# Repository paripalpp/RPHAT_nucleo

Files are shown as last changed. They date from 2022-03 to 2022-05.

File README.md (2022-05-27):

# RPHAT_nucleo
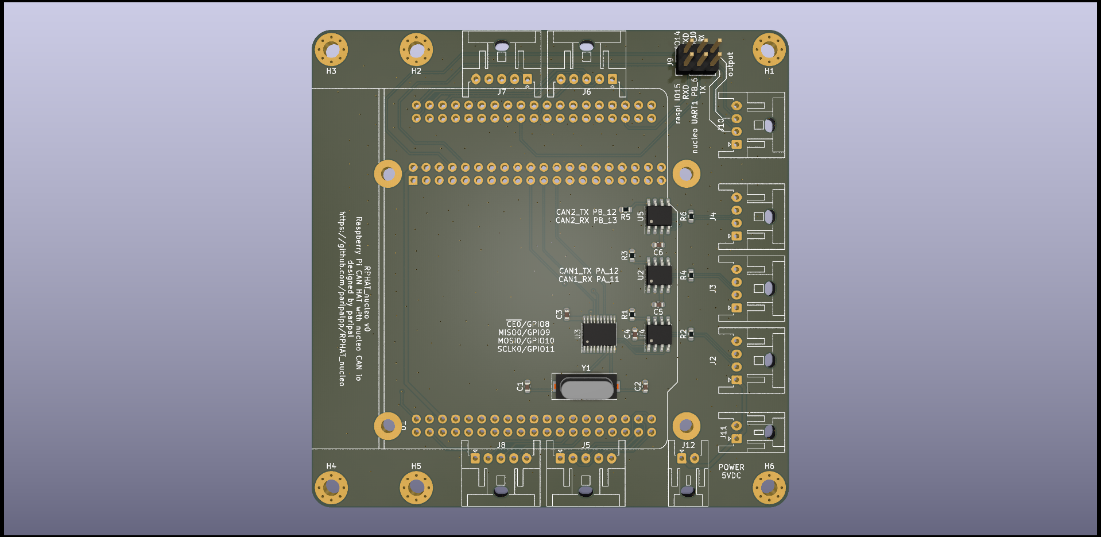
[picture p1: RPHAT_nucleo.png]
3Dimage

# connector
|Connector|pin number|nucleo pin|
|---|---|---|
J5|1|PC_0
J5|2|PC_1
J5|3|PC_2
J5|4|PC_3
J5|5|GND
J6|1|PC_4
J6|2|PC_5
J6|3|PC_6
J6|4|PC_7
J6|5|GND
J7|1|PC_8
J7|2|PC_9
J7|3|PC_10
J7|4|PC_11
J7|5|GND
J8|1|PC_12
J8|2|PC_13
J8|3|PC_14
J8|4|PC_15
J8|5|GND
# 注意！！
V0のボードは CAN2 の PB12 と PB13 がつながってますが、CAN TX と CAN RX が逆なので、使用しない又はプリントを切ってつなぎなおすなどをしてください。
 
V1のボードは解決済み。
# LISENCE
<br />This work is licensed under a <a rel="license" href="http://creativecommons.org/licenses/by/4.0/">Creative Commons Attribution 4.0 International License</a>.
<br />この 作品 は <a rel="license" href="http://creativecommons.org/licenses/by/4.0/">クリエイティブ・コモンズ 表示 4.0 国際 ライセンス</a>の下に提供されています。

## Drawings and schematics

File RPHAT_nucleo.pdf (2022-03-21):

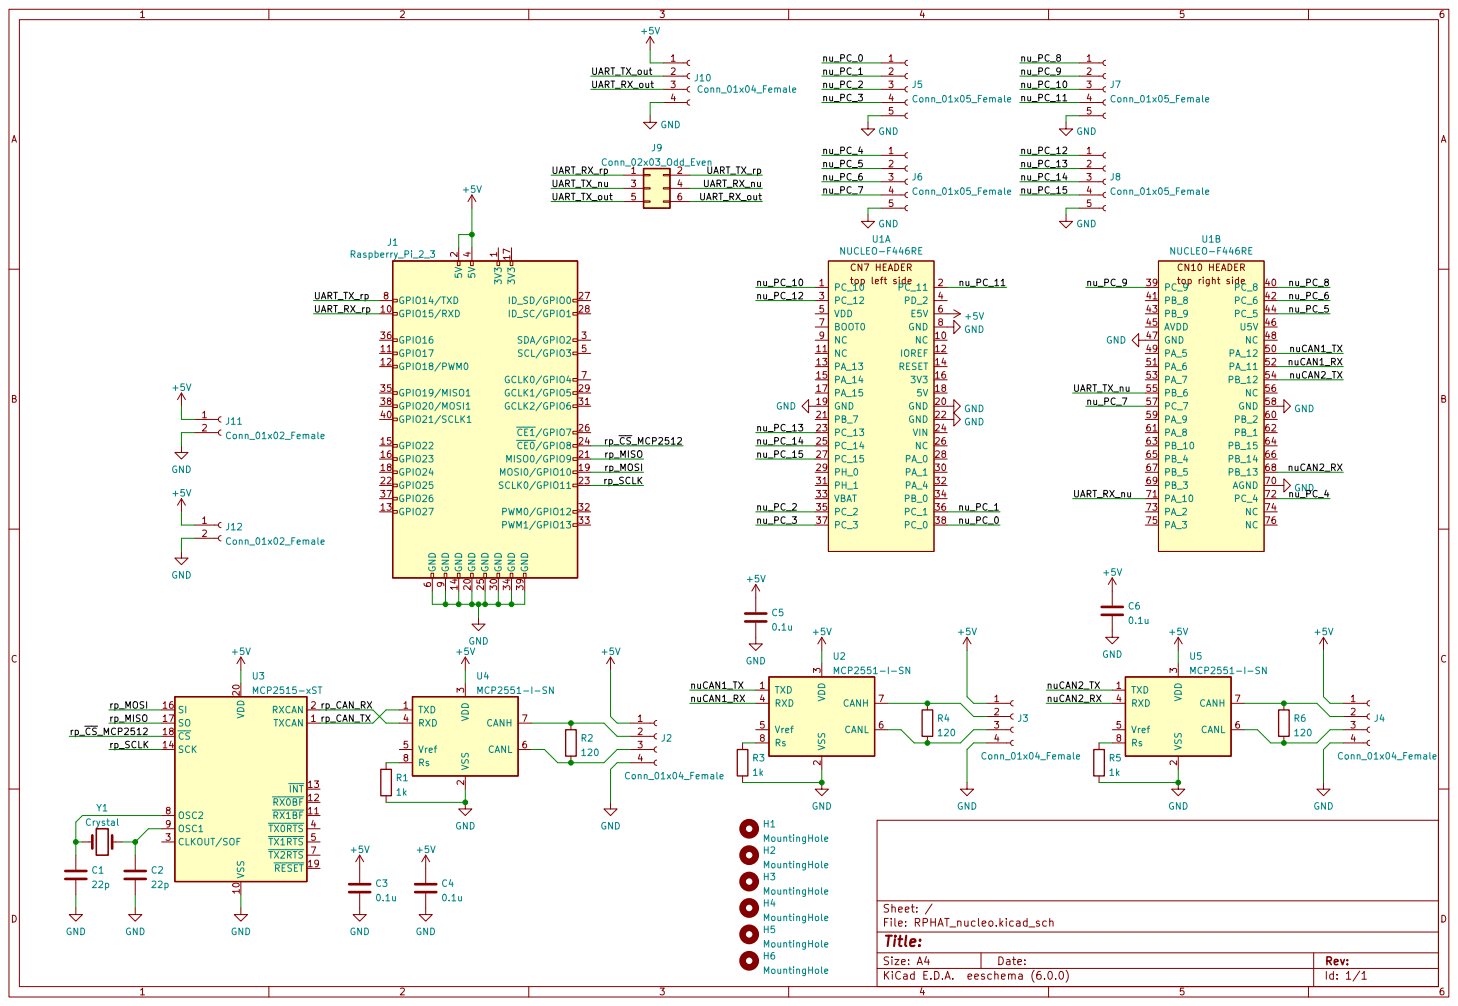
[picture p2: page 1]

3 RXD 4 Vref 5 CANL 6 CANH 7 Rs 8 U2MCP2551-I-SN

3 RXD 4 Vref 5 CANL 6 CANH 7 Rs 8 U5MCP2551-I-SN

3 RXD 4 Vref 5 CANL 6 CANH 7 Rs 8 U4MCP2551-I-SN

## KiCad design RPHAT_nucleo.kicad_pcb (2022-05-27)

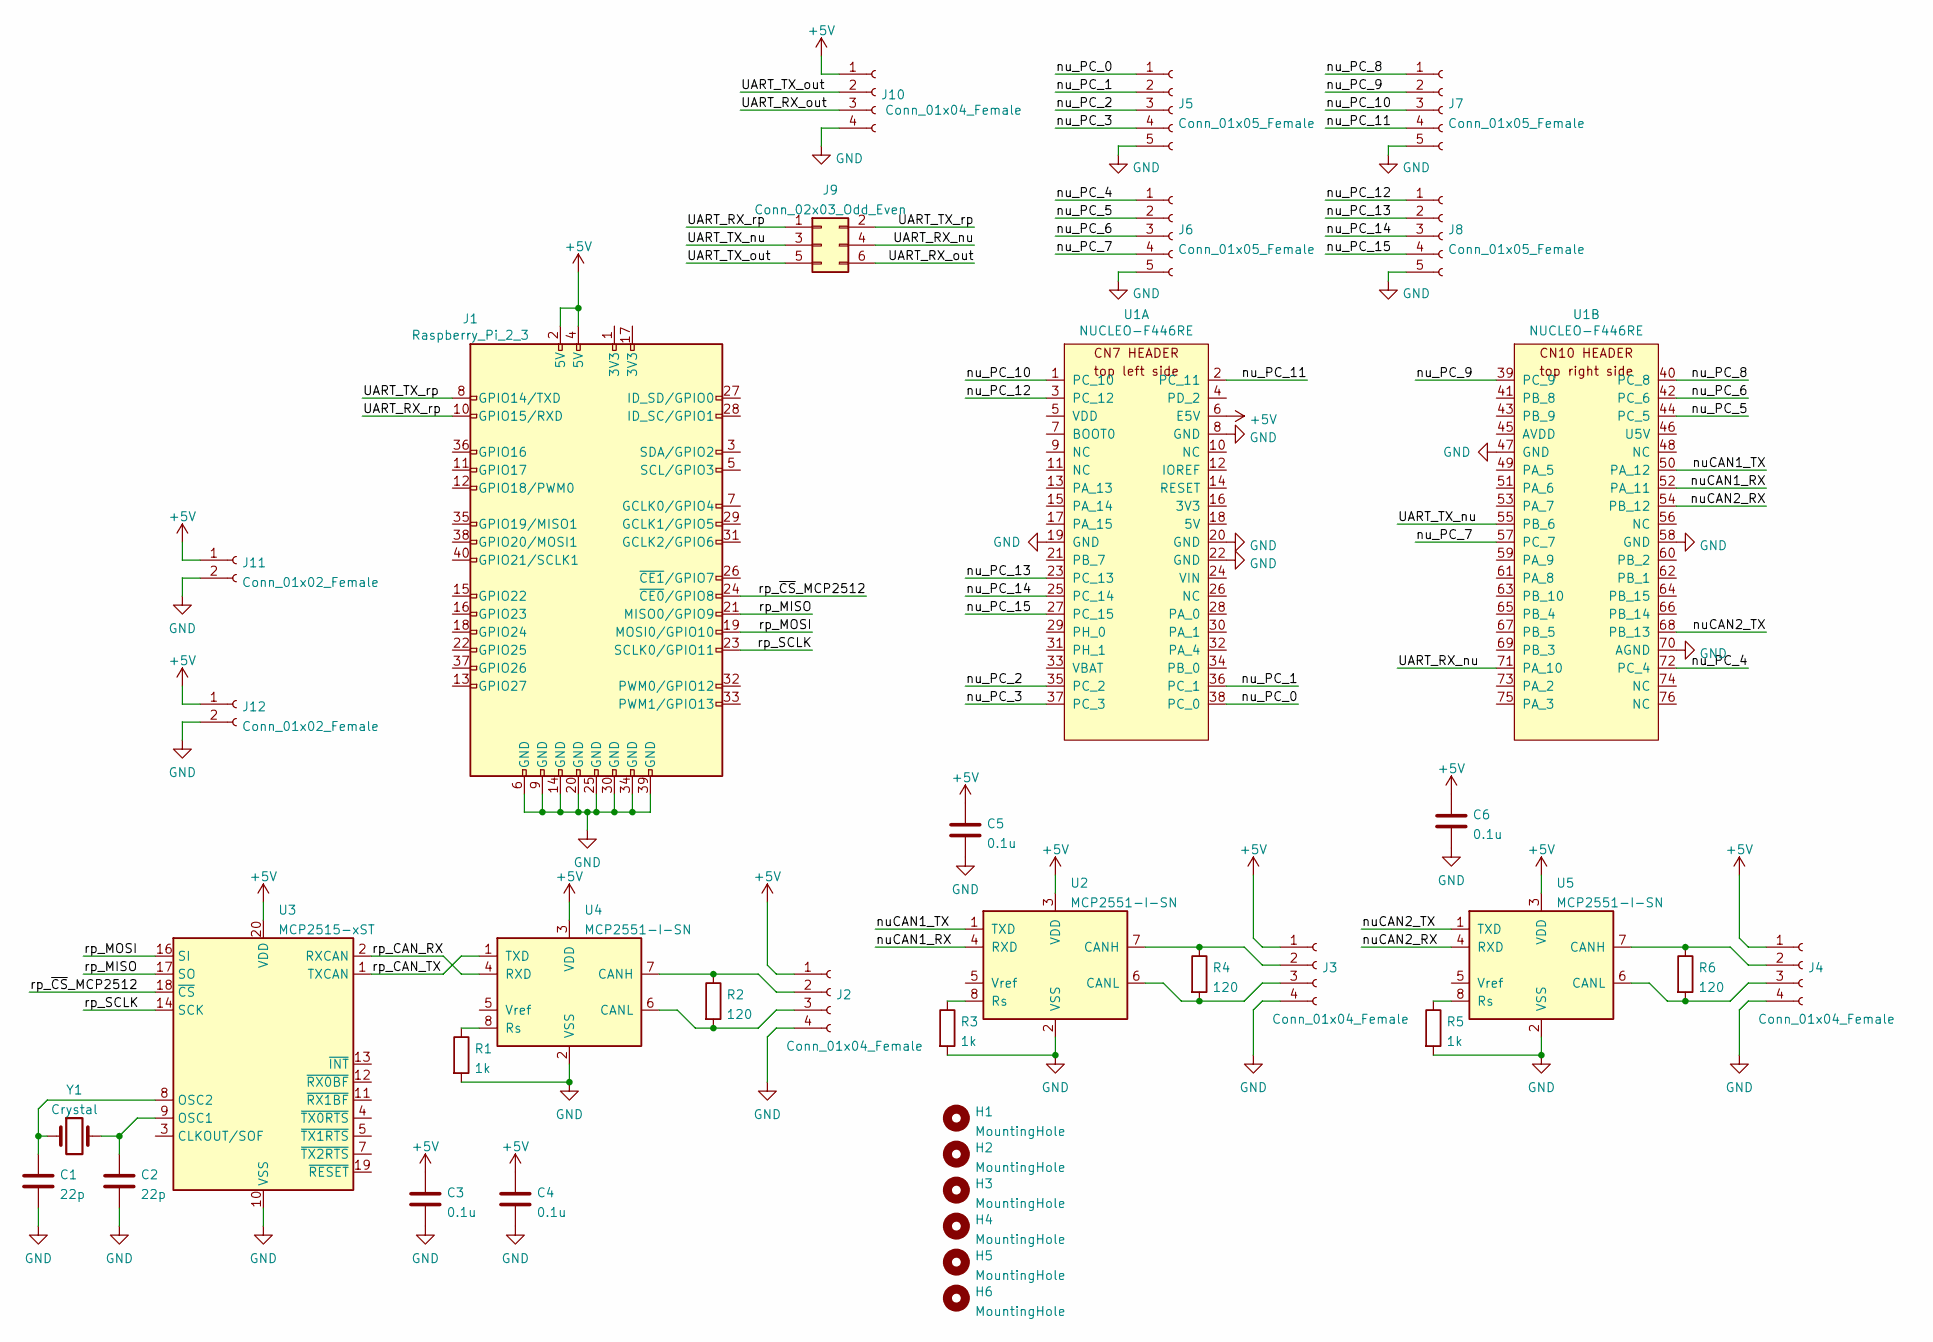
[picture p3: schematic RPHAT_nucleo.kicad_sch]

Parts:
C1, C2: 22p; C_0603_1608Metric
C3, C4, C5, C6: 0.1u; C_0603_1608Metric
H1, H2, H3, H4, H5, H6: MountingHole; MountingHole_3.2mm_M3_Pad_Via
J1: Raspberry_Pi_2_3; RaspberryPi_HAT_Connector_4hole
J2, J3, J4, J10: Conn_01x04_Female; JST_XA_S04B-XASK-1_1x04_P2.50mm_Horizontal
J5, J6, J7, J8: Conn_01x05_Female; JST_XA_S05B-XASK-1_1x05_P2.50mm_Horizontal
J9: Conn_02x03_Odd_Even; PinHeader_2x03_P2.54mm_Vertical
J11, J12: Conn_01x02_Female; JST_XA_S02B-XASK-1_1x02_P2.50mm_Horizontal
R1, R3, R5: 1k; R_0603_1608Metric
R2, R4, R6: 120; R_0603_1608Metric
U1: NUCLEO-F446RE; Nucleo-64_ST_morpho
U2, U4, U5: MCP2551-I-SN; SOIC-8_3.9x4.9mm_P1.27mm
U3: MCP2515-xST; TSSOP-20_4.4x6.5mm_P0.65mm
Y1: Crystal; Crystal_SMD_HC49-SD

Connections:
+5V: C3.1, C4.1, C5.1, C6.1, J1.2 (5V), J1.4 (5V), J2.1, J3.1, J4.1, J10.1, J11.1, J12.1, U1.6 (E5V), U2.3 (VDD), U3.20 (VDD), U4.3 (VDD), U5.3 (VDD)
/UART_RX_nu: J9.4, U1.71 (PA_10)
/UART_RX_out: J9.6, J10.3
/UART_RX_rp: J1.10 (GPIO15/RXD), J9.1
/UART_TX_nu: J9.3, U1.55 (PB_6)
/UART_TX_out: J9.5, J10.2
/UART_TX_rp: J1.8 (GPIO14/TXD), J9.2
/nuCAN1_RX: U1.52 (PA_11), U2.4 (RXD)
/nuCAN1_TX: U1.50 (PA_12), U2.1 (TXD)
/nuCAN2_RX: U1.54 (PB_12), U5.4 (RXD)
/nuCAN2_TX: U1.68 (PB_13), U5.1 (TXD)
/nu_PC_0: J5.1, U1.38 (PC_0)
/nu_PC_1: J5.2, U1.36 (PC_1)
/nu_PC_2: J5.3, U1.35 (PC_2)
/nu_PC_3: J5.4, U1.37 (PC_3)
/nu_PC_4: J6.1, U1.72 (PC_4)
/nu_PC_5: J6.2, U1.44 (PC_5)
/nu_PC_6: J6.3, U1.42 (PC_6)
/nu_PC_7: J6.4, U1.57 (PC_7)
/nu_PC_8: J7.1, U1.40 (PC_8)
/nu_PC_9: J7.2, U1.39 (PC_9)
/nu_PC_10: J7.3, U1.1 (PC_10)
/nu_PC_11: J7.4, U1.2 (PC_11)
/nu_PC_12: J8.1, U1.3 (PC_12)
/nu_PC_13: J8.2, U1.23 (PC_13)
/nu_PC_14: J8.3, U1.25 (PC_14)
/nu_PC_15: J8.4, U1.27 (PC_15)
/rp_CAN_RX: U3.2 (RXCAN), U4.4 (RXD)
/rp_CAN_TX: U3.1 (TXCAN), U4.1 (TXD)
/rp_MISO: J1.21 (MISO0/GPIO9), U3.17 (SO)
/rp_MOSI: J1.19 (MOSI0/GPIO10), U3.16 (SI)
/rp_SCLK: J1.23 (SCLK0/GPIO11), U3.14 (SCK)
/rp_~CS_MCP2512: J1.24 (~CE0/GPIO8), U3.18 (~CS)
GND: C1.2, C2.2, C3.2, C4.2, C5.2, C6.2, J1.6 (GND), J1.9 (GND), J1.14 (GND), J1.20 (GND), J1.25 (GND), J1.30 (GND), J1.34 (GND), J1.39 (GND), J2.4, J3.4, J4.4, J5.5, J6.5, J7.5, J8.5, J10.4, J11.2, J12.2, R1.2, R3.2, R5.2, U1.8 (GND), U1.19 (GND), U1.20 (GND), U1.22 (GND), U1.47 (GND), U1.58 (GND), U1.70 (AGND), U2.2 (VSS), U3.10 (VSS), U4.2 (VSS), U5.2 (VSS)
unnamed: C1.1, U3.8 (OSC2), Y1.1
unnamed: C2.1, U3.9 (OSC1), Y1.2
unnamed: J2.2, R2.1, U4.7 (CANH)
unnamed: J2.3, R2.2, U4.6 (CANL)
unnamed: J3.2, R4.1, U2.7 (CANH)
unnamed: J3.3, R4.2, U2.6 (CANL)
unnamed: J4.2, R6.1, U5.7 (CANH)
unnamed: J4.3, R6.2, U5.6 (CANL)
unnamed: R1.1, U4.8 (Rs)
unnamed: R3.1, U2.8 (Rs)
unnamed: R5.1, U5.8 (Rs)

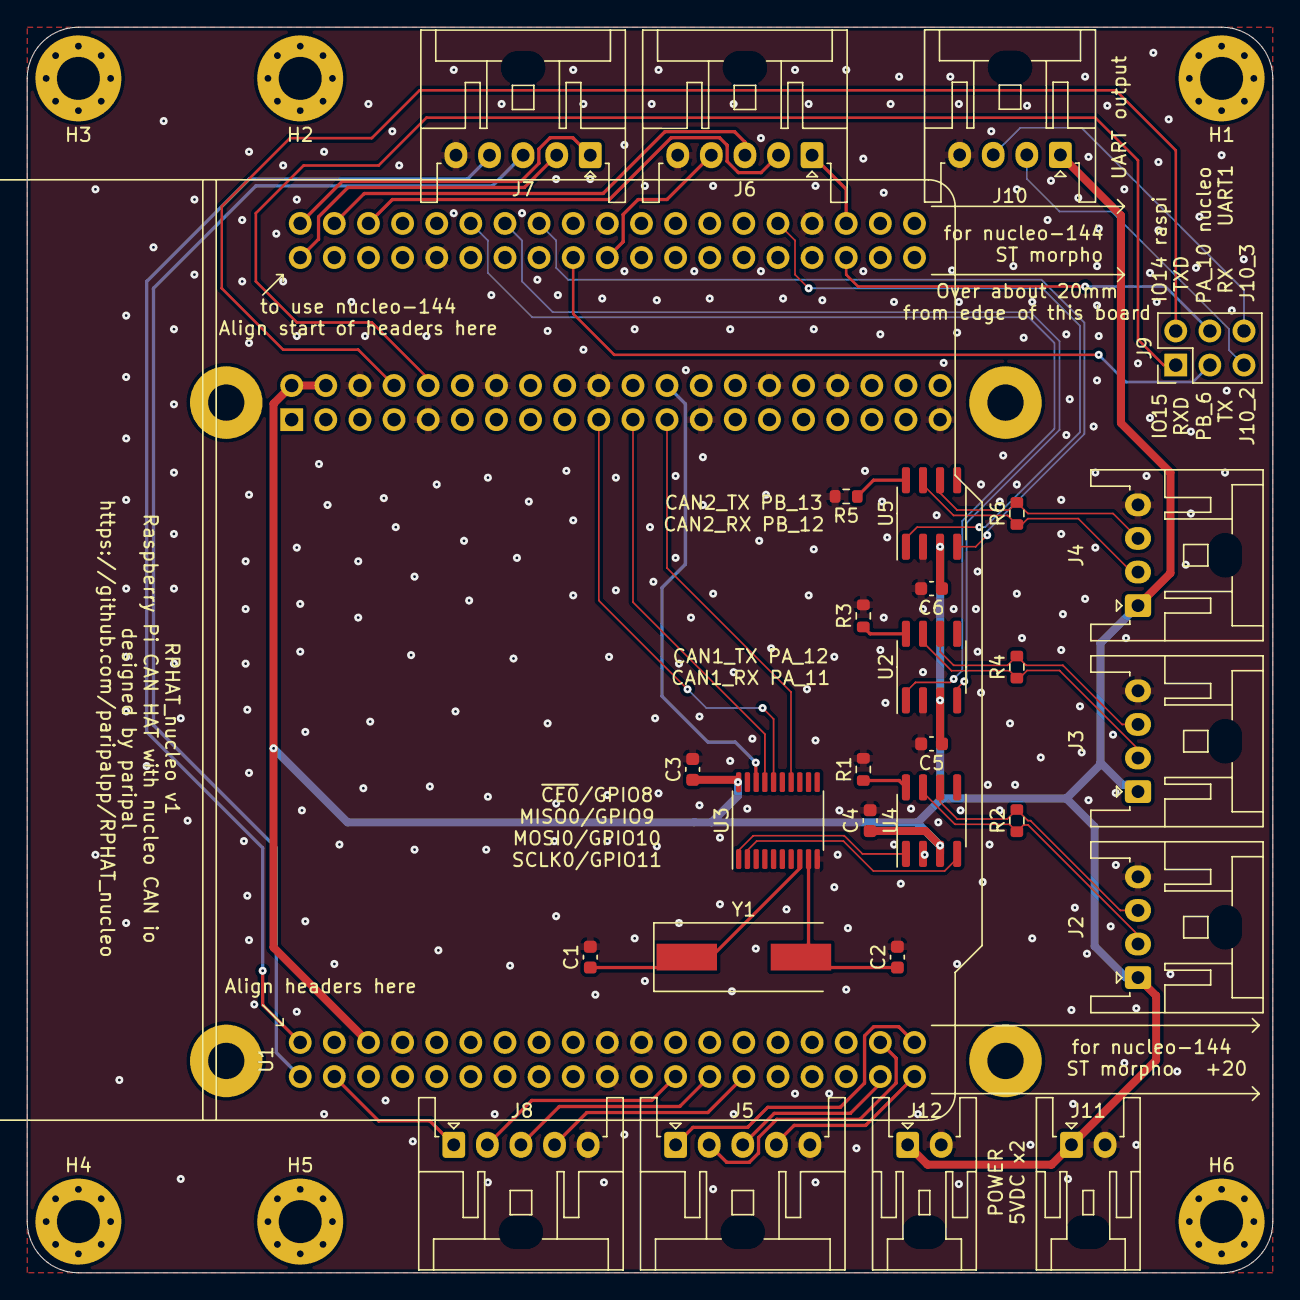
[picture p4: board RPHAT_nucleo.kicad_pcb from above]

Board: 2 copper layers, 92.7 x 92.7 mm, 36 parts (0 on the bottom side), 45 nets.

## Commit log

2021-12-27 to 6.0
    [RPHAT_nucleo.kicad_pcb, RPHAT_nucleo.kicad_sch]
2022-03-18 edit some net class
    [RPHAT_nucleo.kicad_pcb, RPHAT_nucleo.kicad_sch, RPHAT_nucleo.sch]
2022-04-20 Update README.md
    CAN2 の間違った配線の注意書きを追加
2022-05-27 v1 comp
    [RPHAT_nucleo.kicad_pcb, RPHAT_nucleo.kicad_sch]
